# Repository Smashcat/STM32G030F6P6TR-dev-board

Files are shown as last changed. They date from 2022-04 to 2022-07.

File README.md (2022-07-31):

# STM32G030F6P6TR development board
Small breadboard friendly development board for the 32bit STM32G030F6P6TR microcontroller (currently stocked and priced at just over $1 on JLC!) with the following available features:

- 32Kb Flash
- 8Kb RAM.
- 12 bit ADC (16 channels)
- 2 x USART
- 2 x i2C
- i2S
- 2 x SPI
- 17 x GPIOs
- 5 DMA channels for above peripherals, plus memory to memory transfers
- Realtime clock with calendar and alarm with interrupt generation
- 8 x timers
- 2 x watchdogs

Note that many of the peripherals share pins.

This board includes 8 USER LEDs, 2 user buttons, UART to USB bridge, SHT30-DIS-B temperature and humidity sensor and all pins broken out for development use. Pullups on i2C pins. On-board 3.3V regulator from USB supply, with header pins for 3.3V and 5V available for use.

The V1.1 version also includes a LSM6DS3TR IMU device on the i2C bus. Other than this, it is identical.

All files required for full PCBA production at JLCPCB are included in the "Production files" folder.

Example firmware added to show use of i2C sensor, plus LEDs and internal clock.

V1.0
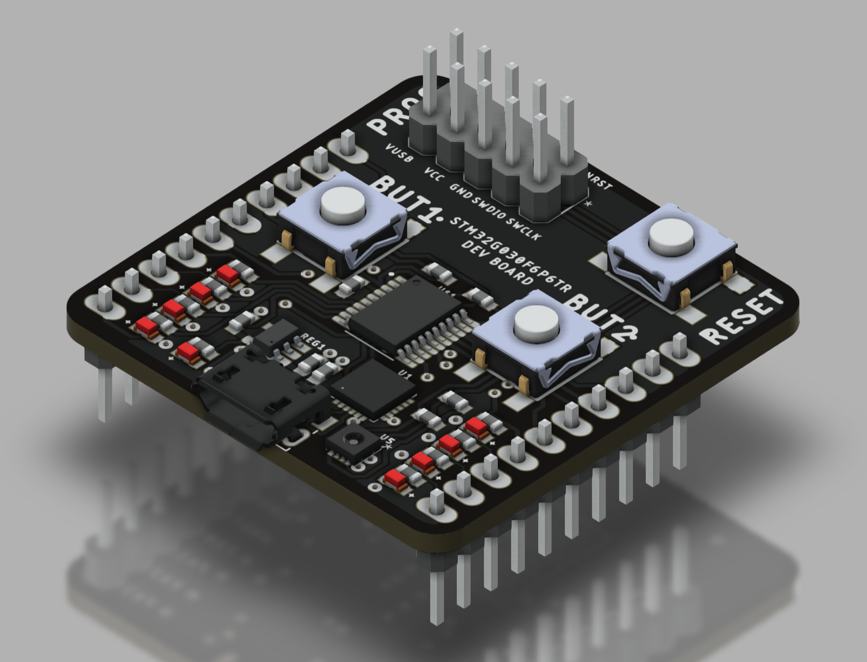
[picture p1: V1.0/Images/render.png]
Render


V1.1 (with IMU)
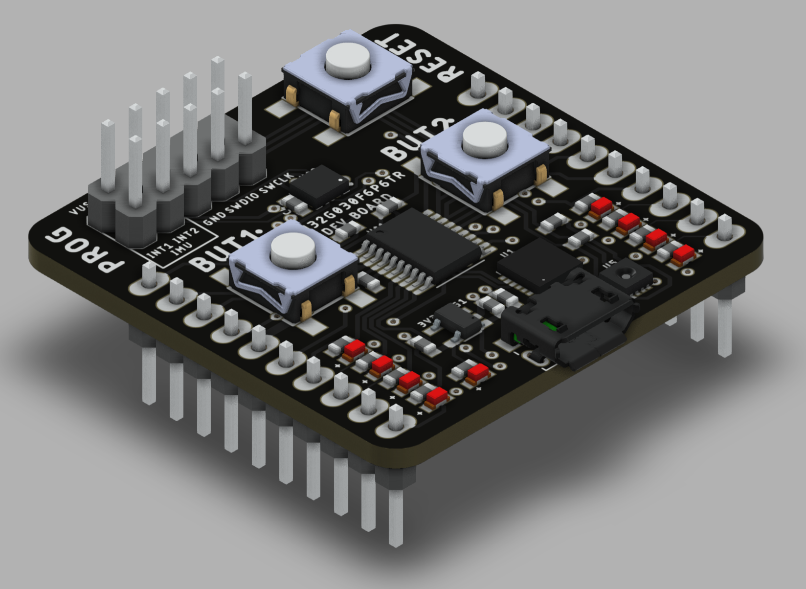
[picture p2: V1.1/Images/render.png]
Render


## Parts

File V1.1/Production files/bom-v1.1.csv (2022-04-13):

Qty | Designator | Footprint | Comment | LCSC Part # | Description | Device
2 | R13, R18 | 52101-101-REV-A_RC-MASTER-SMD_R0603MP | 100R | C22775 | RESISTOR | 52101-101-REV-A_RC-MASTER-SMD_R_0603MP
1 | J1 | FCI_10118193-0001LF | 10118193-0001LF | C132562 | Micro USB B Type Receptacle Check prices | 10118193-0001LF
2 | C2, C5 | RC-MASTER-SMD_C0603MP | 10uF | C96446 | NON-POLARIZED CAP | RC-MASTER-SMD_C_0603MP
9 | R5, R6, R7, R8, R9, R10, R11, R16, R25 | 52101-101-REV-A_RC-MASTER-SMD_R0603MP | 1K | C21190 | RESISTOR | 52101-101-REV-A_RC-MASTER-SMD_R_0603MP
3 | C1, C3, C4 | RC-MASTER-SMD_C0603MP | 1uF | C15849 | NON-POLARIZED CAP | RC-MASTER-SMD_C_0603MP
9 | PA0_LED, PA1_LED, PA2_LED, PA3_LED, PA4_LED, PA5_LED, PA6_LED, PA7_LED, PWR_LED | CHIP-LED0603 | 20mA | C434421 | LED | LEDCHIP-LED0603
1 | 3V3_REG1 | NCP718BSN330T1G | 3V3 | C587158 |  | NCP718BSN330T1G
2 | R3, R4 | 52101-101-REV-A_RC-MASTER-SMD_R0603MP | 3k3 | C22978 | RESISTOR | 52101-101-REV-A_RC-MASTER-SMD_R_0603MP
1 | U1 | QFN50P400X400X80-25N | CP2104-F03-GM | C47742 | Silabs CP2104 USB to UART Bridge | CP2104-F03-GM
1 | U$2 | LSM6DS3TR | LSM6DS3TR-IMU | C967633 |  | LSM6DS3TR-IMU
1 | JP1 | 2X05 | PINHD-2X5 | C225520 | PIN HEADER | PINHD-2X5
3 | BUT0, BUT1, FORCE_RESET | PTS645(SMT) | PTS645SM43SMTR92LFS | C127509 | C & K COMPONENTS - PTS645SM43SMTR92LFS - SWITCH, SPST, 0.05A, 12VDC, SMD, 4.3MM | PTS645SM43SMTR92LFS
1 | U5 | DFN250X250X100-9N | SHT30-DIS-B | C2687423 | SHT3x Series 5.5 V ±3 %RH 0 to 100% Temperature and Humidity Sensor - DFN-8 Check availability | SHT30-DIS-B
1 | U$1 | SOP65P640X120-20N | STM32G030F6P6TR | C529330 |  | STM32G030F6P6TR

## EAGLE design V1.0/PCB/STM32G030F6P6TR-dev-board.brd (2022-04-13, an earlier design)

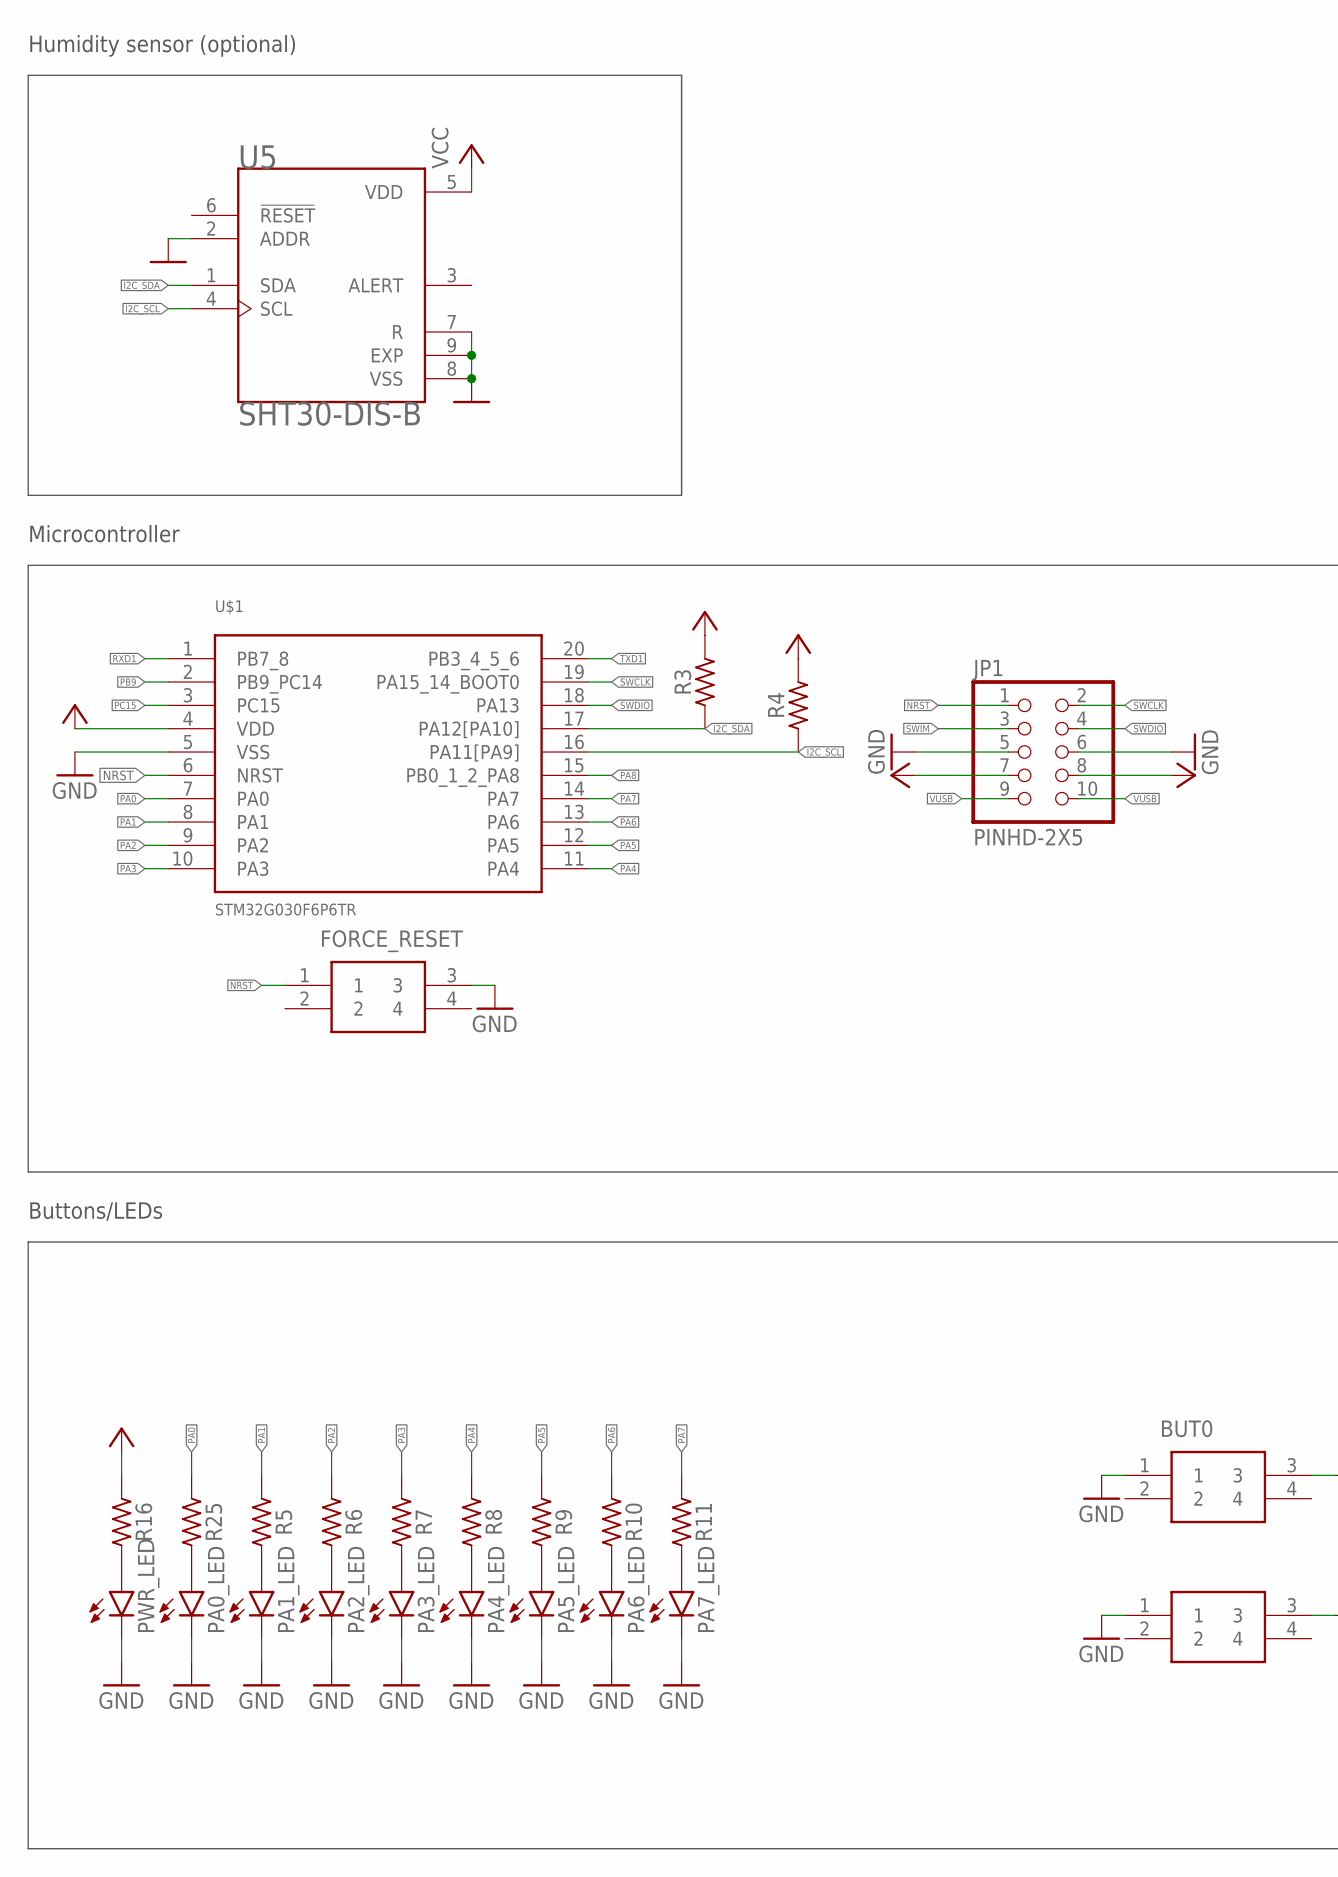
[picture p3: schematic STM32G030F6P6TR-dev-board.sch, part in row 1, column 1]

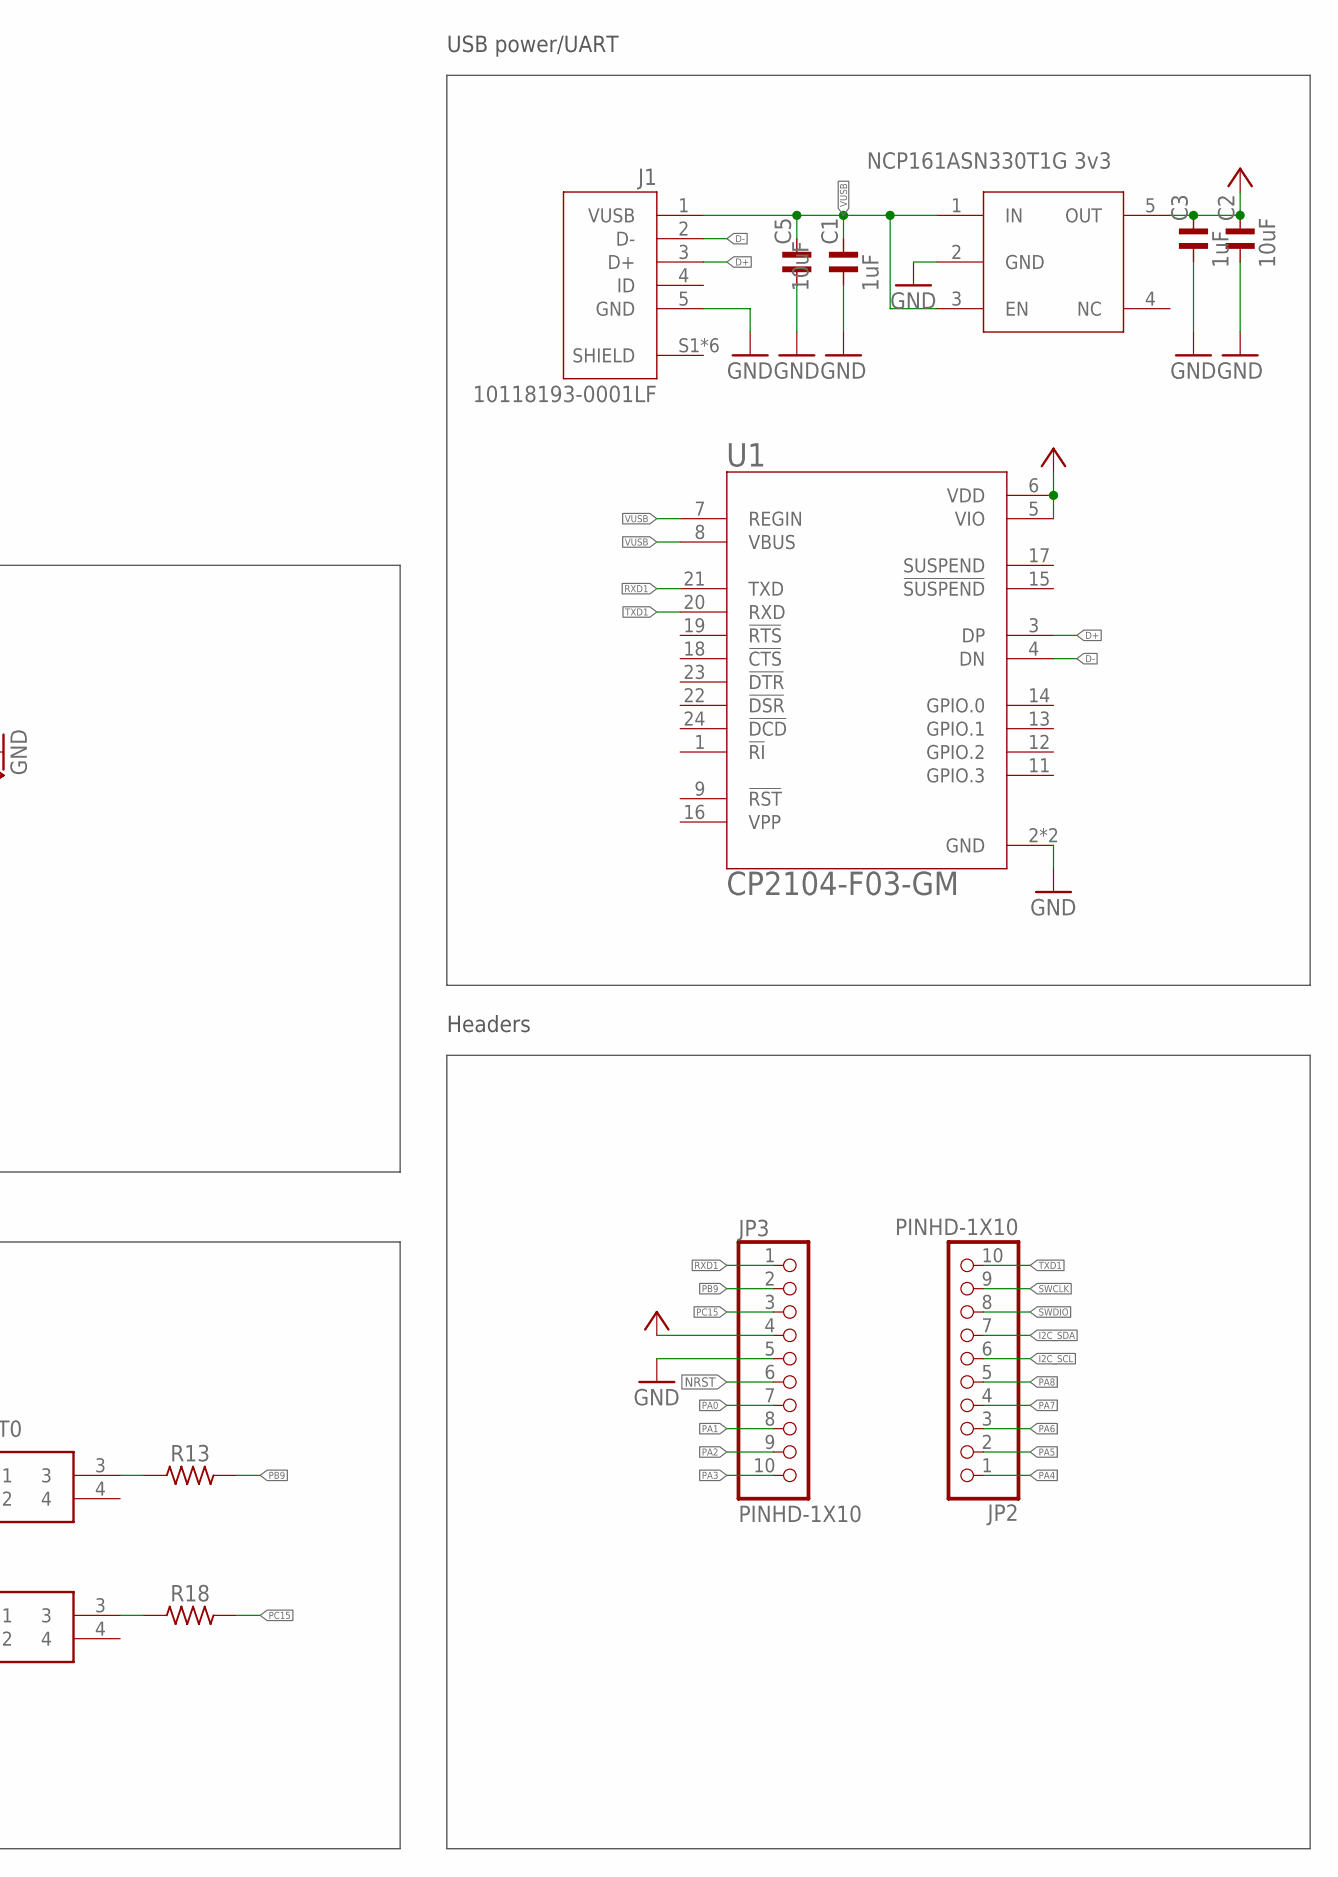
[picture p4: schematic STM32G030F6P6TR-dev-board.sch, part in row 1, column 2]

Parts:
3V3_REG1: 3V3; NCP718BSN330T1G
BUT0, BUT1: PTS645SM43SMTR92LFS; PTS645(SMT)
C1, C3: 1uF; RC-MASTER-SMD_C0603MP
C2, C5: 10uF; RC-MASTER-SMD_C0603MP
FORCE_RESET: PTS645SM43SMTR92LFS; PTS645(SMT)
J1: 10118193-0001LF; FCI_10118193-0001LF
JP1: PINHD-2X5; 2X05
JP2, JP3: PINHD-1X10; 1X10
PA0_LED, PA1_LED, PA2_LED, PA3_LED, PA4_LED, PA5_LED, PA6_LED, PA7_LED: 20mA; CHIP-LED0603
PWR_LED: 20mA; CHIP-LED0603
R3, R4: 3k3; 52101-101-REV-A_RC-MASTER-SMD_R0603MP
R5, R6, R7, R8, R9, R10, R11, R16, R25: 1K; 52101-101-REV-A_RC-MASTER-SMD_R0603MP
R13, R18: 100R; 52101-101-REV-A_RC-MASTER-SMD_R0603MP
U1: CP2104-F03-GM; QFN50P400X400X80-25N
U5: SHT30-DIS-B; DFN250X250X100-9N
U$1: STM32G030F6P6TR; SOP65P640X120-20N

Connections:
D+: J1.3 (D+), U1.3 (DP)
D-: J1.2 (D-), U1.4 (DN)
GND: 3V3_REG1.2 (GND), BUT0.1, BUT1.1, C1.1, C2.1, C3.1, C5.1, FORCE_RESET.3, J1.5 (GND), JP1.5, JP1.6, JP3.5, PA0_LED.C, PA1_LED.C, PA2_LED.C, PA3_LED.C, PA4_LED.C, PA5_LED.C, PA6_LED.C, PA7_LED.C, PWR_LED.C, U1.2 (GND), U1.25 (GND), U5.2 (ADDR), U5.7 (R), U5.8 (VSS), U5.9 (EXP), U$1.5 (VSS)
I2C_SCL: JP2.6, R4.2, U5.4 (SCL), U$1.16 (PA11[PA9])
I2C_SDA: JP2.7, R3.2, U5.1 (SDA), U$1.17 (PA12[PA10])
unnamed: PA1_LED.A, R5.1
unnamed: PA2_LED.A, R6.1
unnamed: PA0_LED.A, R25.1
unnamed: PA3_LED.A, R7.1
unnamed: PA4_LED.A, R8.1
unnamed: PA5_LED.A, R9.1
unnamed: PA6_LED.A, R10.1
unnamed: PA7_LED.A, R11.1
unnamed: BUT0.3, R13.2
unnamed: PWR_LED.A, R16.1
unnamed: BUT1.3, R18.2
NRST: FORCE_RESET.1, JP1.1, JP3.6, U$1.6 (NRST)
PA0: JP3.7, R25.2, U$1.7 (PA0)
PA1: JP3.8, R5.2, U$1.8 (PA1)
PA2: JP3.9, R6.2, U$1.9 (PA2)
PA3: JP3.10, R7.2, U$1.10 (PA3)
PA4: JP2.1, R8.2, U$1.11 (PA4)
PA5: JP2.2, R9.2, U$1.12 (PA5)
PA6: JP2.3, R10.2, U$1.13 (PA6)
PA7: JP2.4, R11.2, U$1.14 (PA7)
PA8: JP2.5, U$1.15 (PB0_1_2_PA8)
PB9: JP3.2, R13.1, U$1.2 (PB9_PC14)
PC15: JP3.3, R18.1, U$1.3 (PC15)
RXD1: JP3.1, U1.21 (TXD), U$1.1 (PB7_8)
SWCLK: JP1.2, JP2.9, U$1.19 (PA15_14_BOOT0)
SWDIO: JP1.4, JP2.8, U$1.18 (PA13)
SWIM: JP1.3
TXD1: JP2.10, U1.20 (RXD), U$1.20 (PB3_4_5_6)
VCC: 3V3_REG1.5 (OUT), C2.2, C3.2, JP1.7, JP1.8, JP3.4, R3.1, R4.1, R16.2, U1.5 (VIO), U1.6 (VDD), U5.5 (VDD), U$1.4 (VDD)
VUSB: 3V3_REG1.1 (IN), 3V3_REG1.3 (EN), C1.2, C5.2, J1.1 (VUSB), JP1.9, JP1.10, U1.7 (REGIN), U1.8 (VBUS)

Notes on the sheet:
Humidity sensor (optional)
NCP161ASN330T1G 3v3
USB power/UART
Microcontroller
Buttons/LEDs
Headers

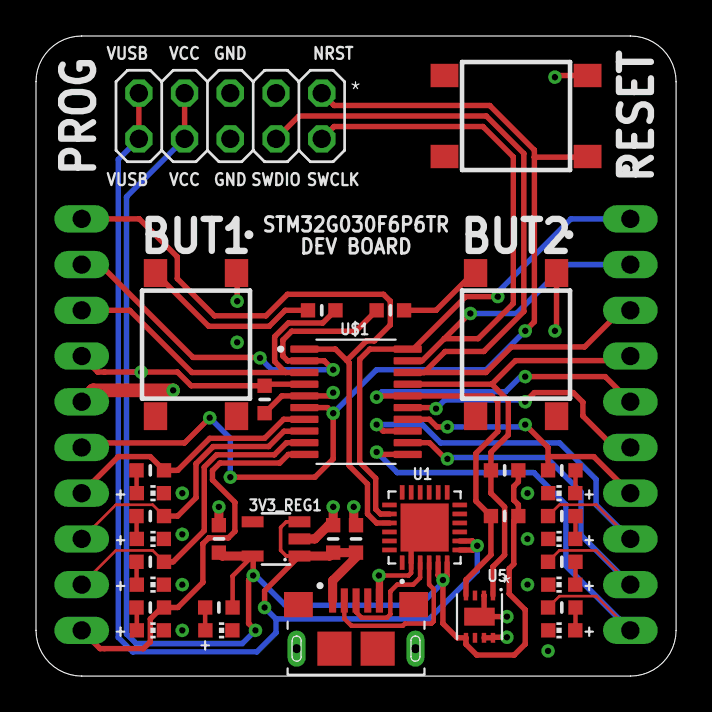
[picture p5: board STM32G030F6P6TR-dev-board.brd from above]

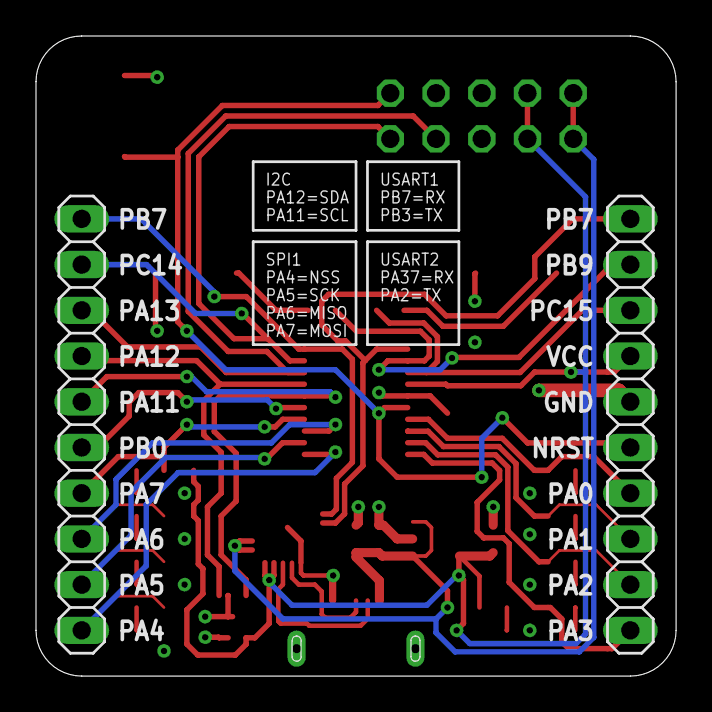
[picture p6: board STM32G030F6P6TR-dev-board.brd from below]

Board: 2 copper layers, 35.6 x 35.6 mm, 37 parts (2 on the bottom side), 34 nets.

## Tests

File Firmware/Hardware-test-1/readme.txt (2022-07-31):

This firmware demonstrates some features of the board:

The 8 LEDs connected to GPIO ports are animated using PWM, via a timer interrupt running at 10Khz
The realtime clock is set and prints to the serial terminal (115200bps 8n1)
The on-board i2C temperature and humidty sensor is polled for the current readings, which are also printed to serial
If either of the two user buttons are pressed, they will also appear in the serial output (updates at 1hz)

This example was put together using STM32Cube IDE version 1.8.0 on Windows.

You will probably need to adjust the output directory by right clicking on the project, then properties, then "Debug/Run settings". Then click on the launch config, and edit.

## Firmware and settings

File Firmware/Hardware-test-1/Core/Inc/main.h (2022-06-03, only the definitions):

#define but2_Pin GPIO_PIN_14
#define but2_GPIO_Port GPIOC
#define but1_Pin GPIO_PIN_15
#define but1_GPIO_Port GPIOC
#define out0_Pin GPIO_PIN_0
#define out0_GPIO_Port GPIOA
#define out1_Pin GPIO_PIN_1
#define out1_GPIO_Port GPIOA
#define out2_Pin GPIO_PIN_2
#define out2_GPIO_Port GPIOA
#define out3_Pin GPIO_PIN_3
#define out3_GPIO_Port GPIOA
#define out4_Pin GPIO_PIN_4
#define out4_GPIO_Port GPIOA
#define out5_Pin GPIO_PIN_5
#define out5_GPIO_Port GPIOA
#define out6_Pin GPIO_PIN_6
#define out6_GPIO_Port GPIOA
#define out7_Pin GPIO_PIN_7
#define out7_GPIO_Port GPIOA
#define SIM_KEY_OUT_Pin GPIO_PIN_8
#define SIM_KEY_OUT_GPIO_Port GPIOA

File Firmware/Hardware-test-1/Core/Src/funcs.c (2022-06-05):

/*
 * funcs.c
 *
 *  Created on: Jun 3, 2022
 *      Author: Scott Porter
 */

#include "funcs.h"

I2C_HandleTypeDef hi2c2;

RTC_HandleTypeDef hrtc;

TIM_HandleTypeDef htim14;

UART_HandleTypeDef huart1;

RTC_DateTypeDef rtcDate;
RTC_TimeTypeDef rtcTime;
uint32_t pTmr=0;
char s[64];

// LED brightnesses, for timer interrupt to use to generate PWM on LED pins
//int8_t ledLevel[8]={0,25,50,75,100,75,50,25};
int8_t ledLevel[8]={ 100,50,0,50, 26,76,74,24 };

// Direction of change for LED brightnesses. The brightness is changed at 100hz
//int8_t ledDir[8]={1,1,1,1,-1,-1,-1,-1};
int8_t ledDir[8]={ -1,-1,1,1, -2,-2,2,2 };
// ticker used in timer interrupt for PWM generation
volatile uint8_t I_ticker=0;

// tock increments at 100hz. Useful for synchronising animation
volatile uint8_t I_tocks=0;

// Sensor readings
float temperature=0;
float humidity=0;

// Sends data to the UART, which is connected to USB. It is set up for 115200bps in this program.
void debugPrint(UART_HandleTypeDef *huart, char _out[]){
 HAL_UART_Transmit(huart, (uint8_t *) _out, strlen(_out), 10);
}

// As above, but also sends a CRLF after the text
void debugPrintln(UART_HandleTypeDef *huart, char _out[]){
 HAL_UART_Transmit(huart, (uint8_t *) _out, strlen(_out), 10);
 char newline[2] = "\r\n";
 HAL_UART_Transmit(huart, (uint8_t *) newline, 2, 10);
}


// Interrupt called at 10Khz, mostly used for PWM, and also increments I_tocks at ~200hz
void HAL_TIM_PeriodElapsedCallback(TIM_HandleTypeDef* htim)
{
	if(++I_ticker==100){
		I_ticker=0;
	}
	if(I_ticker==0 || I_ticker==50){
		++I_tocks;
	}
	volatile uint8_t x=0;
	if(ledLevel[0]>I_ticker) x=1;
	if(ledLevel[1]>I_ticker) x|=(1<<1);
	if(ledLevel[2]>I_ticker) x|=(1<<2);
	if(ledLevel[3]>I_ticker) x|=(1<<3);
	if(ledLevel[4]>I_ticker) x|=(1<<4);
	if(ledLevel[5]>I_ticker) x|=(1<<5);
	if(ledLevel[6]>I_ticker) x|=(1<<6);
	if(ledLevel[7]>I_ticker) x|=(1<<7);
	GPIOA->ODR=x;
}

void doLoop(){
	if(I_tocks){
		I_tocks=0;
		// Update the LED brightnesses at 100hz
		int8_t chg=1;
		for(uint8_t n=0;n<8;n++){
			if(n==4)
				chg=2;
			ledLevel[n]+=ledDir[n];
			if(ledLevel[n]>=100){
				ledLevel[n]=100;
				ledDir[n]=-chg;
			}else if(ledLevel[n]<=0){
				ledLevel[n]=0;
				ledDir[n]=chg;
			}
		}

		// Show the date/time and button states around every second
		if(++pTmr==200){
			uint32_t buts = GPIOC->IDR;
			HAL_RTC_GetTime(&hrtc, &rtcTime, RTC_FORMAT_BIN);//Get time
			HAL_RTC_GetDate(&hrtc, &rtcDate, RTC_FORMAT_BIN);//get date
			sprintf(
				s,
				"%02d/%02d/20%02d %02d:%02d:%02d : %s %s : ",
				rtcDate.Date,rtcDate.Month,rtcDate.Year,
				rtcTime.Hours, rtcTime.Minutes, rtcTime.Seconds,
				(buts&(1<<15)?"----":"BUT1"),
				(buts&(1<<14)?"----":"BUT2")
			);
			debugPrint(&huart1, s);
			pTmr=0;
			uint8_t ret=getHumidityTemp();
			if(ret){
				sprintf(s,"i2C returned: %d\r\n",ret);
			}else{
				// The default compiler settings disable conversion of floating point
				// to text, and enabling it took too much flash memory!
				int32_t t=(temperature*100);
				int32_t h=(humidity*100);
				uint8_t tm=t%100;
				uint8_t hm=h%100;
				int16_t td=(int16_t)t/100;
				int16_t hd=(int16_t)h/100;
				t/=100;
				h/=100;
				sprintf(s,"Temp: %d.%dC, Relative Humidity: %d.%d%%\r\n",td,tm,hd,hm);
			}
			debugPrint(&huart1, s);
		}

	}

}

// Read the temperature and humidity from the on-board SHT30 sensor
uint8_t getHumidityTemp(void){
	uint8_t pData[6]={0x2C,0x06,0,0,0,0};
	uint8_t ret=HAL_I2C_Master_Transmit (&hi2c2, HUMIDITY_SENSOR_ADDR<<1, pData, 2, 10000);
	HAL_Delay(50);
	ret=HAL_I2C_Master_Receive (&hi2c2, HUMIDITY_SENSOR_ADDR<<1, pData, 6, 10000);

	if(ret){
		return ret;
	}

	temperature = ((((pData[0] * 256.0) + pData[1]) * 175) / 65535.0) - 45;
	humidity = ((((pData[3] * 256.0) + pData[4]) * 100) / 65535.0);

	return ret;
}

// Scan for i2C devices
void scanBus(void){
	HAL_Delay(1000);
	char s[16];
	debugPrint(&huart1, "Scanning for i2C devices...\r\n\r\n---- ");
	for(uint8_t i=1; i<128; i++){
		uint8_t ret = HAL_I2C_IsDeviceReady(&hi2c2, (uint16_t)(i<<1), 3, 5);
		if (ret != HAL_OK) /* No ACK Received At That Address */
		{
			sprintf(s, "---- ");
		}
		else if(ret == HAL_OK)
		{
			sprintf(s, "0x%02X ", i);
		}
		if((i%16)==15){
			debugPrintln(&huart1, s);
		}else{
			debugPrint(&huart1, s);
		}
	}
	debugPrintln(&huart1, "\r\nDone\r\n");
}

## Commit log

2022-04-10 Updated render, revered mounting headers
    [STM32G030F6P6TR-test.brd]
2022-04-12 Updated board layout by reversing pin header to bottom side. Added datasheet for MCU
2022-04-13 Added IMU version (1.1)
    [STM32G030F6P6TR-dev-board-plus-imu.brd, STM32G030F6P6TR-dev-board-plus-imu.sch, STM32G030F6P6TR-dev-board.brd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]
2022-06-03 Deleted old directories
    [STM32G030F6P6TR-test.brd, STM32G030F6P6TR-test.sch, bom.csv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]
2022-06-05 Slight change to LED animation

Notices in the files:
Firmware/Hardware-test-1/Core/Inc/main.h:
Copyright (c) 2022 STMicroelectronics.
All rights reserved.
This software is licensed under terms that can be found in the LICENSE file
